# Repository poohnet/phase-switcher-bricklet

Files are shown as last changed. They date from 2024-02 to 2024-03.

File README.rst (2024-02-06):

Phase Switcher Bricklet
=======================

**This Bricklet is currently in development.**

This repository contains the firmware source code and the hardware design
files. The documentation generator configs can be found at
https://github.com/Tinkerforge/generators

Repository Content
------------------

software/:
 * examples/: Examples for all supported languages
 * build/: Compiled files
 * src/: Source code of firmware
 * Makefile: Makefile to build project

hardware/:
 * Contains KiCad project files and additionally schematics as PDF

datasheets/:
 * Contains datasheets for sensors and complex ICs that are used

Hardware
--------

The hardware is designed with the open source EDA Suite KiCad
(http://www.kicad.org). Before you are able to open the files,
you have to install the Tinkerforge kicad-libraries
(https://github.com/Tinkerforge/kicad-libraries). You can either clone
them directly in hardware/ or clone them in a separate folder and
symlink them into hardware/
(ln -s kicad_path/kicad-libraries project_path/hardware). After that you
can open the .pro file in hardware/ with KiCad and from there view and
modify the schematics and the PCB layout.

Software
--------

If you want to do your own Brick/Bricklet firmware development we highly
recommend that you use our build environment setup script and read the
tutorial (https://www.tinkerforge.com/en/doc/Tutorials/Tutorial_Build_Environment/Tutorial.html).

To compile the C code we recommend you to install the newest GNU Arm Embedded
Toolchain (https://launchpad.net/gcc-arm-embedded/+download).
You also need to install bricklib2 (https://github.com/Tinkerforge/bricklib2).

You can either clone it directly in software/src/ or clone it in a
separate folder and symlink it into software/src/
(ln -s bricklib_path/bricklib2 project_path/software/src/). Finally make sure to
have CMake installed (http://www.cmake.org/cmake/resources/software.html).

After that you can build the firmware by invoking make in software/.
The firmware (.zbin) can then be found in software/build/ and uploaded
with brickv (click button "Flashing" on start screen).

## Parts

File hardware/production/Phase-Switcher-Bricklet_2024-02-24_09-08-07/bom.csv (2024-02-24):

Designator | Footprint | Quantity | Value | LCSC Part #
C1 | C0805 | 1 | 10uF | C1222438
C2 | C0603 | 1 | 1uF | C513775
C3 | C0402 | 1 | 220pF | C107025
C4 | C0603 | 1 | 100nF | C30926
CN1 | CONN-SMD_7P-P1.25_HCTL_HC-GH-7PWTKK | 1 | HC-GH-7PWTKK | C3011949
D10, D20 | SOD-123FL_L2.8-W1.8-LS3.7-RD | 2 | 1N4007 | C2902912
LED1, LED2, LED3, LED4, LED5, LED6 | LED0603-RD | 6 | blue | C84266
P10 | CONN-TH_4P-P3.81_KF124-3.81-4P | 1 | WJ124-3.81-4P | C69809
P11, P21, P30 | CONN-TH_2P-P3.81_KF124-3.81-2P | 3 | WJ124-3.81-2P | C69811
R1, R10, R2, R20, R3, R30, R4, R5, R6 | R0603 | 9 | 1K | C22548
R11, R21 | R0603 | 2 | 150 | C114608
R12, R22 | RES-TH_L12.5-W6.2-P7.50-D0.9-S6.20 | 2 | 10D391K | C139984
R13, R23 | RES-TH_BD2.2-L6.5-P10.50-D0.6 | 2 | RN1/2WS249KΩFT/BA1 | C385480
RN1 | RES-ARRAY-SMD_0603-8P-L3.2-W1.6-BL | 1 | CRA034RJ82RP05 | C429276
RN2 | RES-ARRAY-SMD_0603-8P-L3.2-W1.6-BL | 1 | 10K | C396839
U1 | VQFN-24_L4.0-W4.0-P0.50-TL-EP2.7 | 1 | XMC1302-Q024X0032-AB | C5121285
U10, U20 | DIP-8_7P-L9.7-W6.4-P2.54-LS7.6-BL-PE7 | 2 | AQH2223 | C128520
U11, U21 | DIP-8_L9.4-W6.4-P2.54-LS9.1-BL | 2 | 6N139M | C4071
U30 | SOP-4_L4.3-W4.4-P2.54-LS7.0-BL | 1 | AQY282SX | C250827

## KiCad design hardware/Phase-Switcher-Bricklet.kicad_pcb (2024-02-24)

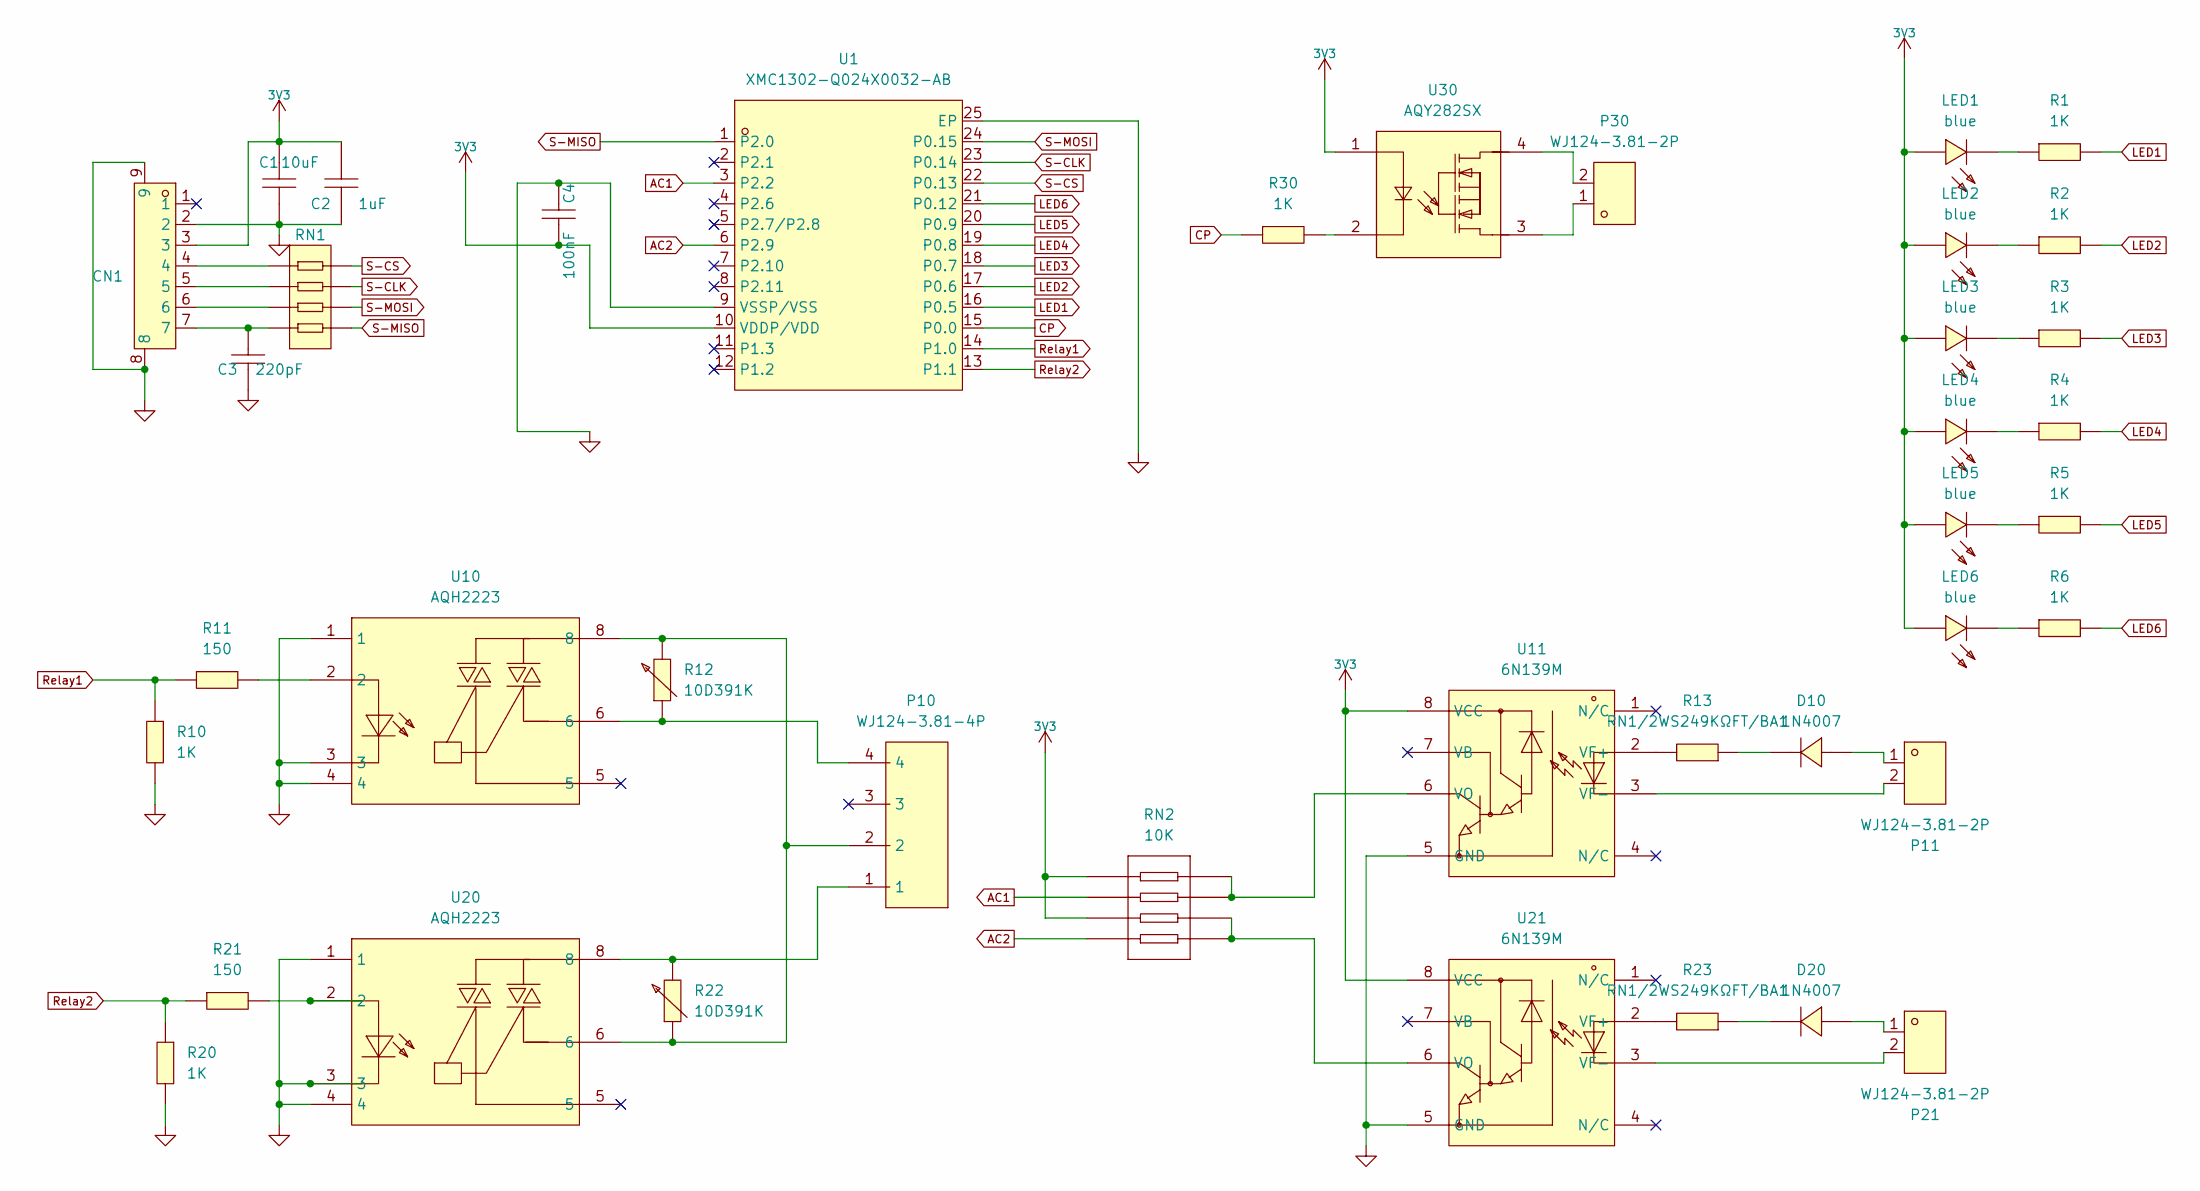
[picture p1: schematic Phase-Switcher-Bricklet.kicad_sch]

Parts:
C1: 10uF; C0805; LCSC Part C1222438
C2: 1uF; C0603; LCSC Part C513775
C3: 220pF; C0402; LCSC Part C107025
C4: 100nF; C0603; LCSC Part C30926
CN1: HC-GH-7PWTKK; CONN-SMD_7P-P1.25_HCTL_HC-GH-7PWTKK; LCSC Part C3011949
D10, D20: 1N4007; SOD-123FL_L2.8-W1.8-LS3.7-RD; LCSC Part C2902912
LED1, LED2, LED3, LED4, LED5, LED6: blue; LED0603-RD; LCSC Part C84266
P10: WJ124-3.81-4P; CONN-TH_4P-P3.81_KF124-3.81-4P; LCSC Part C69809
P11, P21, P30: WJ124-3.81-2P; CONN-TH_2P-P3.81_KF124-3.81-2P; LCSC Part C69811
R1, R2, R3, R4, R5, R6, R10, R20, R30: 1K; R0603; LCSC Part C22548
R11, R21: 150; R0603; LCSC Part C114608
R12, R22: 10D391K; RES-TH_L12.5-W6.2-P7.50-D0.9-S6.20; LCSC Part C139984
R13, R23: RN1/2WS249KΩFT/BA1; RES-TH_BD2.2-L6.5-P10.50-D0.6; LCSC Part C385480
RN1: CRA034RJ82RP05; RES-ARRAY-SMD_0603-8P-L3.2-W1.6-BL; LCSC Part C429276
RN2: 10K; RES-ARRAY-SMD_0603-8P-L3.2-W1.6-BL; LCSC Part C396839
U1: XMC1302-Q024X0032-AB; VQFN-24_L4.0-W4.0-P0.50-TL-EP2.7; LCSC Part C5121285
U10, U20: AQH2223; DIP-8_7P-L9.7-W6.4-P2.54-LS7.6-BL-PE7; LCSC Part C128520
U11, U21: 6N139M; DIP-8_L9.4-W6.4-P2.54-LS9.1-BL; LCSC Part C4071
U30: AQY282SX; SOP-4_L4.3-W4.4-P2.54-LS7.0-BL; LCSC Part C250827

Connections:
3V3: C1.1, C2.1, C4.2, CN1.3, LED1.2 (+), LED2.2 (+), LED3.2 (+), LED4.2 (+), LED5.2 (+), LED6.2 (+), RN2.5, RN2.7, U1.10 (VDDP/VDD), U11.8 (VCC), U21.8 (VCC), U30.1
AC1: RN2.6, U1.3 (P2.2)
AC2: RN2.8, U1.6 (P2.9)
CP: R30.1, U1.15 (P0.0)
GND: C1.2, C2.2, C3.2, C4.1, CN1.2, CN1.8, CN1.9, R10.2, R20.2, U1.9 (VSSP/VSS), U1.25 (EP), U10.1, U10.3, U10.4, U11.5 (GND), U20.1, U20.3, U20.4, U21.5 (GND)
LED1: R1.2, U1.16 (P0.5)
LED2: R2.2, U1.17 (P0.6)
LED3: R3.2, U1.18 (P0.7)
LED4: R4.2, U1.19 (P0.8)
LED5: R5.2, U1.20 (P0.9)
LED6: R6.2, U1.21 (P0.12)
unnamed: C3.1, CN1.7, RN1.4
unnamed: CN1.4, RN1.1
unnamed: CN1.5, RN1.2
unnamed: CN1.6, RN1.3
unnamed: D10.2 (A), P11.1
unnamed: D10.1 (K), R13.1
unnamed: D20.2 (A), P21.1
unnamed: D20.1 (K), R23.1
unnamed: LED1.1 (-), R1.1
unnamed: LED2.1 (-), R2.1
unnamed: LED3.1 (-), R3.1
unnamed: LED4.1 (-), R4.1
unnamed: LED5.1 (-), R5.1
unnamed: LED6.1 (-), R6.1
unnamed: P10.1, R22.2, U20.8
unnamed: P10.2, R12.2, R22.1, U10.8, U20.6
unnamed: P10.4, R12.1, U10.6
unnamed: P30.1, U30.3
unnamed: P30.2, U30.4
unnamed: R11.2, U10.2
unnamed: R21.2, U20.2
unnamed: R30.2, U30.2
unnamed: R13.2, U11.2 (VF+)
unnamed: P11.2, U11.3 (VF-)
unnamed: RN2.3, RN2.4, U11.6 (VO)
unnamed: R23.2, U21.2 (VF+)
unnamed: P21.2, U21.3 (VF-)
unnamed: RN2.1, RN2.2, U21.6 (VO)
Relay1: R10.1, R11.1, U1.14 (P1.0)
Relay2: R20.1, R21.1, U1.13 (P1.1)
S-CLK: RN1.7, U1.23 (P0.14)
S-CS: RN1.8, U1.22 (P0.13)
S-MISO: RN1.5, U1.1 (P2.0)
S-MOSI: RN1.6, U1.24 (P0.15)

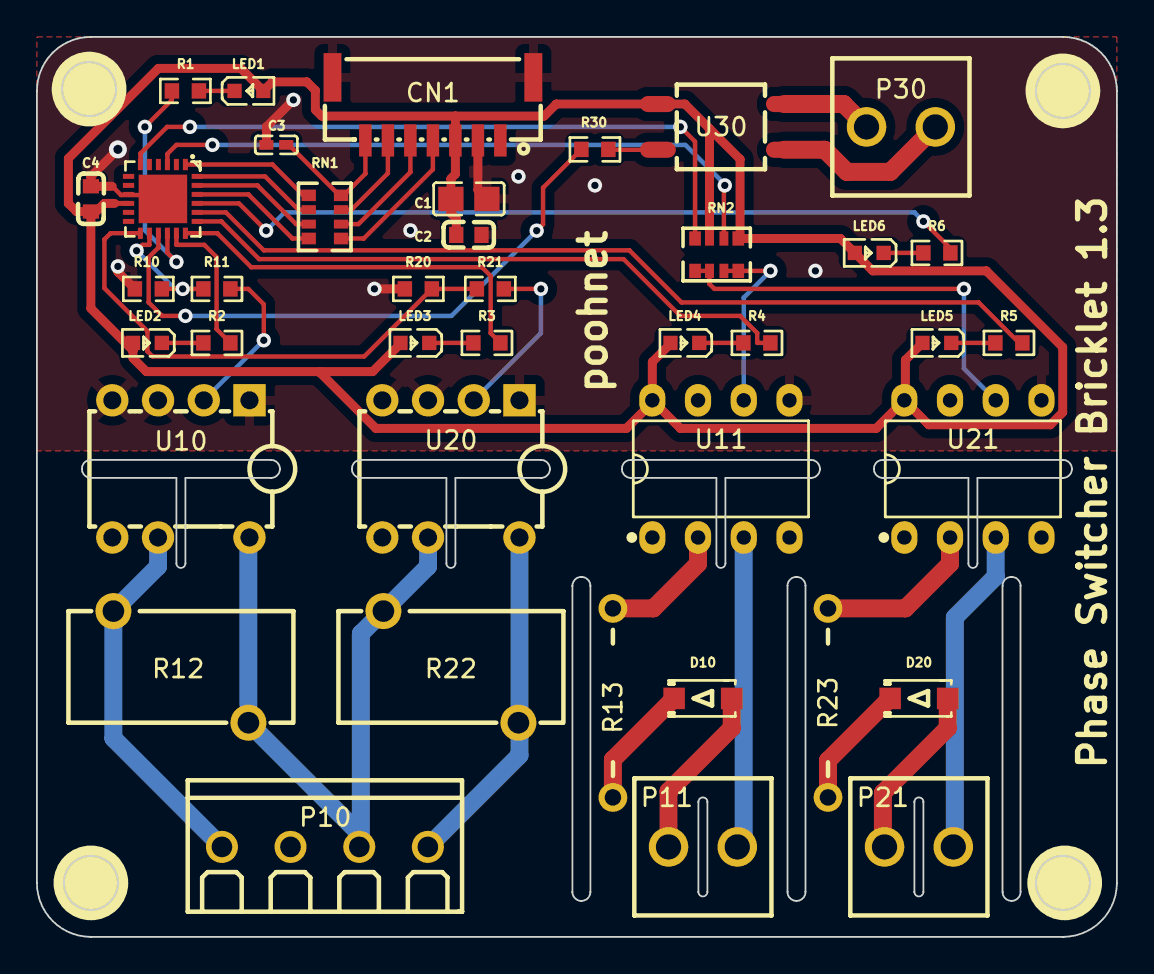
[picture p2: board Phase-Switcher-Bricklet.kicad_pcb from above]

Board: 2 copper layers, 60.0 x 50.0 mm, 40 parts (0 on the bottom side), 45 nets.

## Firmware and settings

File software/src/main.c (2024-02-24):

/* phase-switcher-bricklet
 * Copyright (C) 2024 Thomas Hein <github@poohnet.de>
 *
 * main.c: Initialization for Phase Switcher Bricklet
 *
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
 * You should have received a copy of the GNU Lesser General Public
 * License along with this library; if not, write to the
 * Free Software Foundation, Inc., 59 Temple Place - Suite 330,
 * Boston, MA 02111-1307, USA.
 */

#include <stdio.h>
#include <stdbool.h>

#include "configs/config.h"

#include "bricklib2/bootloader/bootloader.h"
#include "bricklib2/hal/system_timer/system_timer.h"
#include "communication.h"

int main(void)
{
  communication_init();

  while (true) {
    bootloader_tick();
    communication_tick();
  }
}

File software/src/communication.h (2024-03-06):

/* phase-switcher-bricklet
 * Copyright (C) 2024 Thomas Hein <github@poohnet.de>
 *
 * communication.h: TFP protocol message handling
 *
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
 * You should have received a copy of the GNU Lesser General Public
 * License along with this library; if not, write to the
 * Free Software Foundation, Inc., 59 Temple Place - Suite 330,
 * Boston, MA 02111-1307, USA.
 */

#ifndef COMMUNICATION_H
#define COMMUNICATION_H

#include <stdint.h>
#include <stdbool.h>

#include "bricklib2/protocols/tfp/tfp.h"
#include "bricklib2/bootloader/bootloader.h"

// Default functions
BootloaderHandleMessageResponse handle_message(const void *data, void *response);
void communication_tick(void);
void communication_init(void);

// Constants

#define PHASE_SWITCHER_CHANNEL_LED_CONFIG_OFF 0
#define PHASE_SWITCHER_CHANNEL_LED_CONFIG_ON 1
#define PHASE_SWITCHER_CHANNEL_LED_CONFIG_SHOW_HEARTBEAT 2
#define PHASE_SWITCHER_CHANNEL_LED_CONFIG_SHOW_CHANNEL_STATUS 3

#define PHASE_SWITCHER_BOOTLOADER_MODE_BOOTLOADER 0
#define PHASE_SWITCHER_BOOTLOADER_MODE_FIRMWARE 1
#define PHASE_SWITCHER_BOOTLOADER_MODE_BOOTLOADER_WAIT_FOR_REBOOT 2
#define PHASE_SWITCHER_BOOTLOADER_MODE_FIRMWARE_WAIT_FOR_REBOOT 3
#define PHASE_SWITCHER_BOOTLOADER_MODE_FIRMWARE_WAIT_FOR_ERASE_AND_REBOOT 4

#define PHASE_SWITCHER_BOOTLOADER_STATUS_OK 0
#define PHASE_SWITCHER_BOOTLOADER_STATUS_INVALID_MODE 1
#define PHASE_SWITCHER_BOOTLOADER_STATUS_NO_CHANGE 2
#define PHASE_SWITCHER_BOOTLOADER_STATUS_ENTRY_FUNCTION_NOT_PRESENT 3
#define PHASE_SWITCHER_BOOTLOADER_STATUS_DEVICE_IDENTIFIER_INCORRECT 4
#define PHASE_SWITCHER_BOOTLOADER_STATUS_CRC_MISMATCH 5

#define PHASE_SWITCHER_STATUS_LED_CONFIG_OFF 0
#define PHASE_SWITCHER_STATUS_LED_CONFIG_ON 1
#define PHASE_SWITCHER_STATUS_LED_CONFIG_SHOW_HEARTBEAT 2
#define PHASE_SWITCHER_STATUS_LED_CONFIG_SHOW_STATUS 3

// Function and callback IDs and structs
#define FID_SET_CONTROL_PILOT_DISCONNECT 1
#define FID_SET_PHASES_WANTED 2
#define FID_GET_ALL_DATA 3


typedef struct {
	TFPMessageHeader header;
	bool control_pilot_disconnect;
} __attribute__((__packed__)) SetControlPilotDisconnect;

typedef struct {
	TFPMessageHeader header;
	uint8_t phases_wanted;
} __attribute__((__packed__)) SetPhasesWanted;

typedef struct {
	TFPMessageHeader header;
} __attribute__((__packed__)) GetAllData;

typedef struct {
	TFPMessageHeader header;
	bool is_control_pilot_disconnected;
	uint8_t phases_wanted;
	uint8_t phases_active;
} __attribute__((__packed__)) GetAllData_Response;


// Function prototypes
BootloaderHandleMessageResponse set_control_pilot_disconnect(const SetControlPilotDisconnect *data);
BootloaderHandleMessageResponse set_phases_wanted(const SetPhasesWanted *data);
BootloaderHandleMessageResponse get_all_data(const GetAllData *data, GetAllData_Response *response);

// Callbacks


#define COMMUNICATION_CALLBACK_TICK_WAIT_MS 1
#define COMMUNICATION_CALLBACK_HANDLER_NUM 0
#define COMMUNICATION_CALLBACK_LIST_INIT \


#endif

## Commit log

2024-02-06 Add KiCad files and datasheets
    [Phase-Switcher-Bricklet.kicad_pcb, Phase-Switcher-Bricklet.kicad_sch]
2024-02-18 Phase-Switcher-Bricklet: Rev. 1.1
    [Phase-Switcher-Bricklet.kicad_pcb, Phase-Switcher-Bricklet.kicad_sch]
2024-02-21 Phase-Switcher-Bricklet: Rev. 1.1a
    [Phase-Switcher-Bricklet.kicad_pcb, Phase-Switcher-Bricklet.kicad_sch]
2024-02-22 Phase-Switcher-Bricklet: Rev. 1.2
    [Phase-Switcher-Bricklet.kicad_pcb, Phase-Switcher-Bricklet.kicad_sch]
2024-02-24 Phase-Switcher-Bricklet: Rev. 1.3
    [Phase-Switcher-Bricklet.kicad_pcb, Phase-Switcher-Bricklet.kicad_sch, bom.csv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]
2024-02-24 Add firmware stub
    [cmake_config_custom.txt]
